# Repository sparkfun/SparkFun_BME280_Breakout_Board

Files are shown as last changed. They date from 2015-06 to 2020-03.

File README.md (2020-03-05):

SparkFun BME280
===============

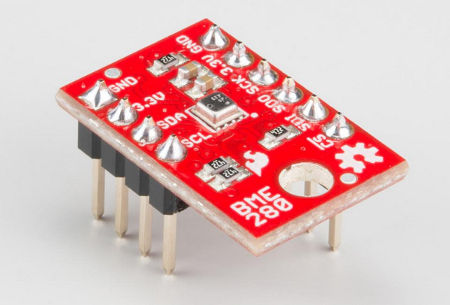
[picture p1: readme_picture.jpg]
SparkFun BME280 Breakout


[*SparkFun BME280 (SEN-13676)*](https://www.sparkfun.com/products/13676)

The Bosch BME280 sensor measures atmospheric pressure from 30kPa to 110kPa as well as relative humidity and temperature.  The SparkFun breakout provides a 3.3v SPI interface and a 5v tolerant I2C interface (has pull-up resistors to 3.3v).

Repository Contents
-------------------

* **/Documentation** - Data sheets, additional product information
* **/Hardware** - Eagle design files (.brd, .sch)
* **/Production** - Production panel files (.brd)

Documentation
--------------
* **[Library](https://github.com/sparkfun/SparkFun_BME280_Arduino_Library)** - Arduino library for the BME280.
* **[Hookup Guide](https://learn.sparkfun.com/tutorials/bme280-breakout-hookup-guide)** - Basic hookup guide for the SparkFun BME280.
* **[SparkFun Fritzing repo](https://github.com/sparkfun/Fritzing_Parts)** - Fritzing diagrams for SparkFun products.
* **[SparkFun 3D Model repo](https://github.com/sparkfun/3D_Models)** - 3D models of SparkFun products. 

Product Versions
----------------
* [*SEN-13676*](https://www.sparkfun.com/products/13676)

Version History
---------------

* [V_1.0.0](https://github.com/sparkfun/SparkFun_BME280_Breakout_Board/tree/V_1.0.0) - Public release.
* [V_1.1.0](https://github.com/sparkfun/SparkFun_BME280_Breakout_Board/tree/V_1.1.0) - Squashed arduino library changes.

License Information
-------------------

This product is _**open source**_! 

Please review the LICENSE.md file for license information. 

If you have any questions or concerns on licensing, please contact techsupport@sparkfun.com.

Distributed as-is; no warranty is given.

- Your friends at SparkFun.

_<COLLABORATION CREDIT>_

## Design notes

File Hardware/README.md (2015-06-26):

SparkFun <PRODUCT NAME> Design Files
=====================================

The .sch and .brd files hare are Eagle CAD schematic and PCB design files from SparkFun Electronics.
A freeware version of Eagle can be found [here](http://www.cadsoftusa.com/download-eagle/freeware/).

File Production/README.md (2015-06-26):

SparkFun <PRODUCT NAME> Production Files
=========================================

These are the production files SparkFun uses for printing PCBs.

License Information
-------------------
This product is open source! 

The hardware is released under [Creative Commons ShareAlike 4.0 International](https://creativecommons.org/licenses/by-sa/4.0/).

Please use, reuse, and modify these files as you see fit. Please maintain attribution to SparkFun Electronics and release anything derivative under the same license.

Distributed as-is; no warranty is given.

- Your friends at SparkFun.

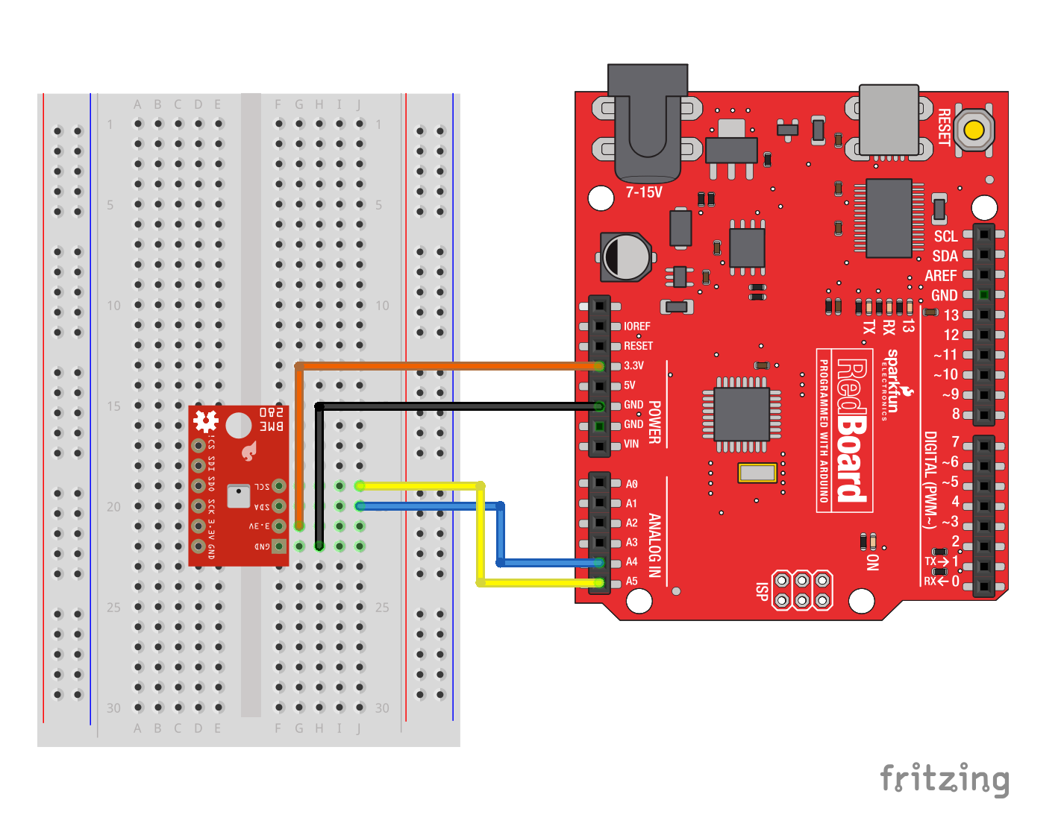
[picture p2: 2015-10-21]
Documentation/Fritzing/RedboardI2C_bb.png

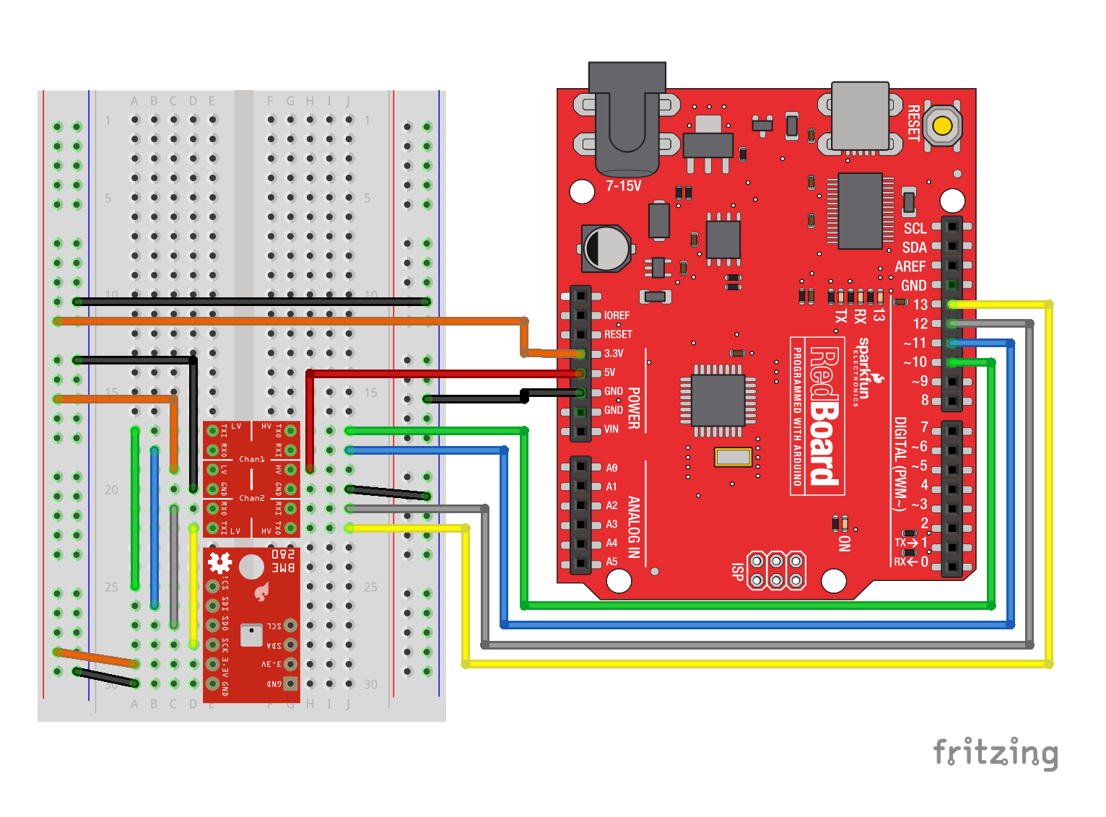
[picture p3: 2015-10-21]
Documentation/Fritzing/RedboardSPI_bb.png

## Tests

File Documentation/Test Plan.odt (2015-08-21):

# Functional Testing Plan

## Code Things to Verify

- Are the readings beliveable over I2C @ 100 KHz?
- Are the readings believable over SPI?
- All address options function with driver

## HW Things to Verify

- Power consumption
- I2C signal integrity
- SPI signal integrity

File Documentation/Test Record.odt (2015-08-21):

# Functional Test Record

Marshall Taylor

8/21/2015

HW version v02

## Testing with I2C mode

#### Test the I2C Addressing

Procedure:

1. Use ReadAllData sketch with default HW
2. Test default condition
3. Switch address jumper
4. Change address in code
5. Test alternate address

Criteria:

1. Did the modes work? YES
2. Does the silkscreen match the operation? YES

#### Signal Integrity of I2C lines

Procedure:

1. Attach scope probes to SDA and SCL with the shortest wire possible
2. Capture a full operation
3. Capture a zoom of 3 consecutively toggling SDA bits

Criteria:

1. Are I2C interface rise times are far below clk pulse high width?
2. Record the pullup resistor value as measured:
- 1: 4.692 kOhm
- 2: 4.698 kOhm

## Testing with SPI mode

Procedure:

1. Connect the BME280 to an arduino through the level shifter
2. Attach scope probes to MOSI, MISO, CS, and CLK on the BME280 side
3. Capture a full operation
4. Capture a zoom of 3 consecutively toggling data bits for MISO
5. Capture a zoom of 3 consecutively toggling data bits for MOSI

Criteria:

1. Does the clock phase and polarity match the datasheets? YES, phase defined by clk state after SS goes low
2. Include the captures.

## Power Consumption

Procedure:

1. Measure the current draw before the IC is configured
2. Configure and spam read the data
3. Measure the current draw during spam read

Criteria:

1. Are both numbers below 5mA?
2. Record both currents
- Idle: ~1.5mA
- Max: ~2.0mA

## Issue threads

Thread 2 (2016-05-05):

readFloatHumidity doesn't return decimals

TheAustrian, 2016-05-05:
Hi! First of all thanks for the library!

I used the code from one of your examples to read the humidity into an array I initialized as follows:
`float humidityBuffer[buffersize+1] = {0.0};`
and later I read from the sensor with:
`humidityBuffer[bufferposition] = mySensor.readFloatHumidity();`
and I get values like "38" but with no decimal places. It works for temperature and with a division by 100 for pressure in hectopascals as well.

What am I doing wrong or is this an error in the library? I'm using the version from the library manager in Arduino IDE.

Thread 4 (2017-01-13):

Humidity randomly starts reading incorrectly

handsomedave, 2017-01-13:
I have two ESP8266 Things with one each BME280 on each device. They are reading Temp/Humidity/Pressure with i2c and logging it to a web service. Randomly one of them will start reading about 50% higher than the other. If I power cycle the Thing it then reads correctly for a random amount of time before again reading incorrectly. It has started to read incorrectly in as little as 5 minutes or as much as 20 hours. I doesn't slowly start drifting away from a correct reading, it just all at once jumps 50% or so.

I have swapped sensors between devices and it seems to only occur with one of the Things regardless of which sensor is hooked up. Other than the two constants used to identify the specific device and sensor the code running on the Things is identical.

santaimpersonator, 2019-12-30:
Based on your explanation of your issue, it sounds like it is an issue with the "ESP8266 Thing". I am closing out this GitHub issue since it doesn't sound like it is related to the BME280; feel free to re-open the issue if necessary. Otherwise, if you are looking for technical assistance, please create a post on our [forum](https://forum.sparkfun.com/).

Closed 2019-12-30.

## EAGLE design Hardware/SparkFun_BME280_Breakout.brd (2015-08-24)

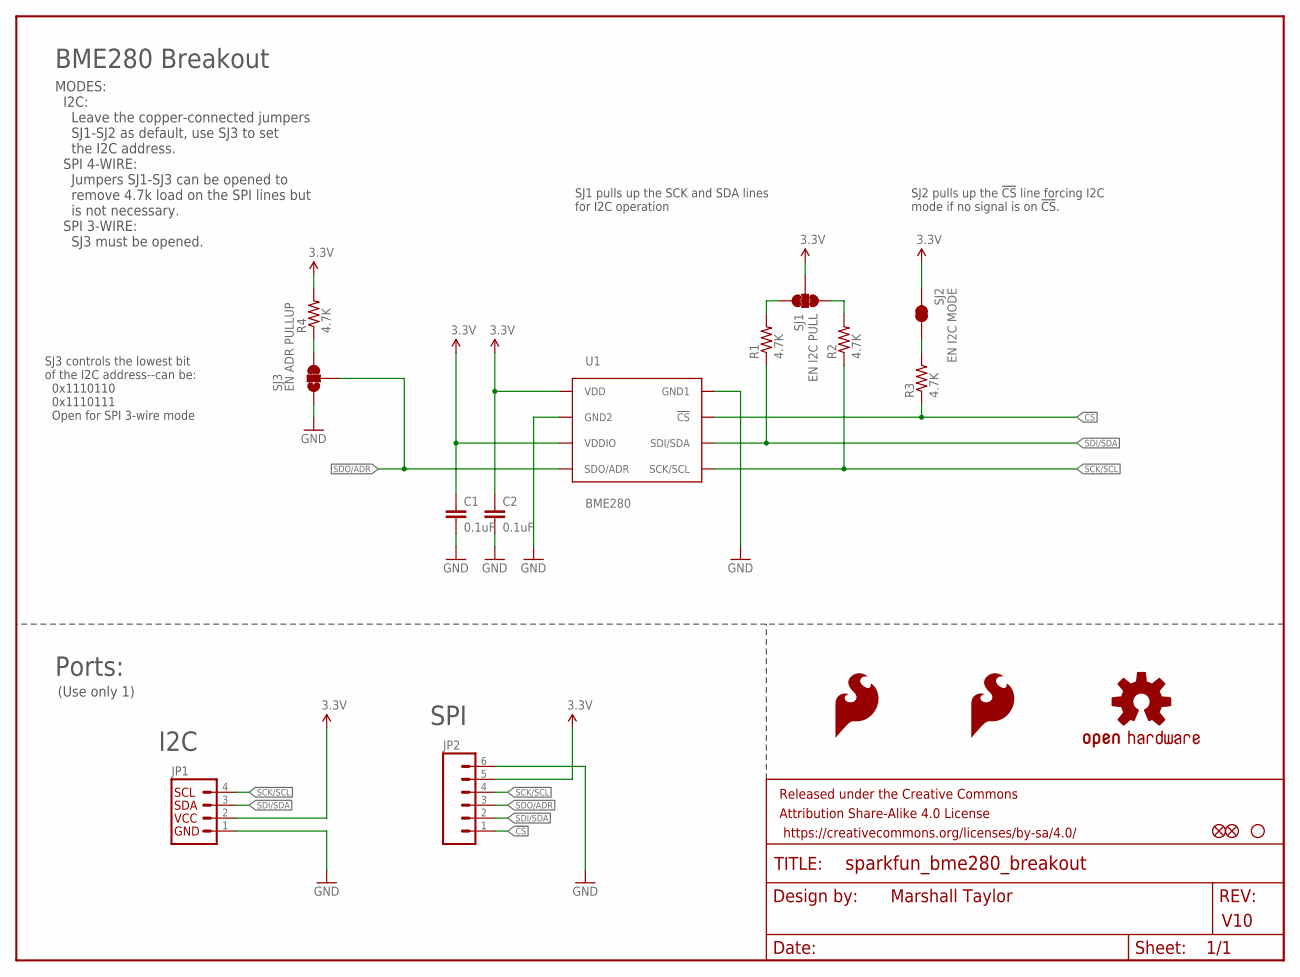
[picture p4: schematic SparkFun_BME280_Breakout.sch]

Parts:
C1, C2: 0.1uF; 0603-CAP
FID1, FID2: FIDUCIAL1X2; FIDUCIAL-1X2
FRAME1: FRAME-LETTER; CREATIVE_COMMONS
JP1: I2C_STANDARD_NO_SILK; 1X04_NO_SILK
JP2: M06NO_SILK_FEMALE_PTH; 1X06_NO_SILK
LOGO1, LOGO2: SFE_LOGO_FLAME.1_INCH; SFE_LOGO_FLAME_.1
LOGO3: OSHW-LOGOS; OSHW-LOGO-S
R1, R2, R3, R4: 4.7K; 0603-RES
SJ1: EN I2C PULL; PAD-JUMPER-3-3OF3_NC_BY_TRACE_YES_SILK_FULL_BOX
SJ2: EN I2C MODE; PAD-JUMPER-2-NC_BY_TRACE_YES_SILK
SJ3: EN ADR PULLUP; PAD-JUMPER-3-2OF3_NC_BY_TRACE_YES_SILK_FULL_BOX
STANDOFF4: STAND-OFF
U1: BME280; BME280_LGA

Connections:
3.3V: C1.1, C2.1, JP1.2, JP2.5, R4.2, SJ1.2, SJ2.2, U1.P$6 (VDDIO), U1.P$8 (VDD)
!CS: JP2.1, R3.1, U1.P$2 (!CS)
GND: C1.2, C2.2, JP1.1, JP2.6, SJ3.1, U1.P$1 (GND1), U1.P$7 (GND2)
unnamed: R1.2, SJ1.3
unnamed: R2.2, SJ1.1
unnamed: R3.2, SJ2.1
unnamed: R4.1, SJ3.3
SCK/SCL: JP1.4, JP2.4, R2.1, U1.P$4 (SCK/SCL)
SDI/SDA: JP1.3, JP2.2, R1.1, U1.P$3 (SDI/SDA)
SDO/ADR: JP2.3, SJ3.2, U1.P$5 (SDO/ADR)

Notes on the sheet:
Marshall Taylor
V10
BME280 Breakout
SJ3 controls the lowest bit of the I2C address--can be: 0x1110110 0x1110111 Open for SPI 3-wire mode
SJ1 pulls up the SCK and SDA lines for I2C operation
Ports:
(Use only 1)
I2C
SPI
MODES: I2C: Leave the copper-connected jumpers SJ1-SJ2 as default, use SJ3 to set the I2C address. SPI 4-WIRE: Jumpers SJ1-SJ3 can be opened to remove 4.7k load on the SPI lines but is not necessary. SPI 3-WIRE: SJ3 must be opened.
SJ2 pulls up the !CS! line forcing I2C mode if no signal is on !CS!.

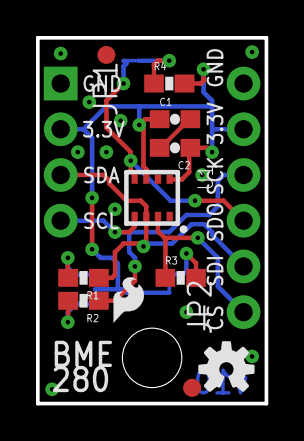
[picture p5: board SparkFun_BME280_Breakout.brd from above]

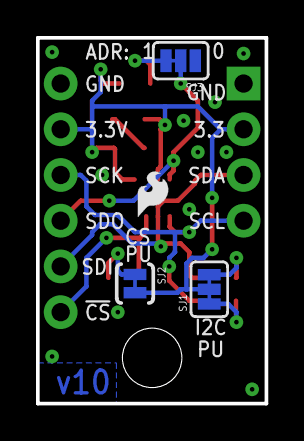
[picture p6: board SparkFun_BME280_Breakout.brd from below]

Board: 2 copper layers, 12.7 x 20.3 mm, 19 parts (4 on the bottom side), 10 nets.

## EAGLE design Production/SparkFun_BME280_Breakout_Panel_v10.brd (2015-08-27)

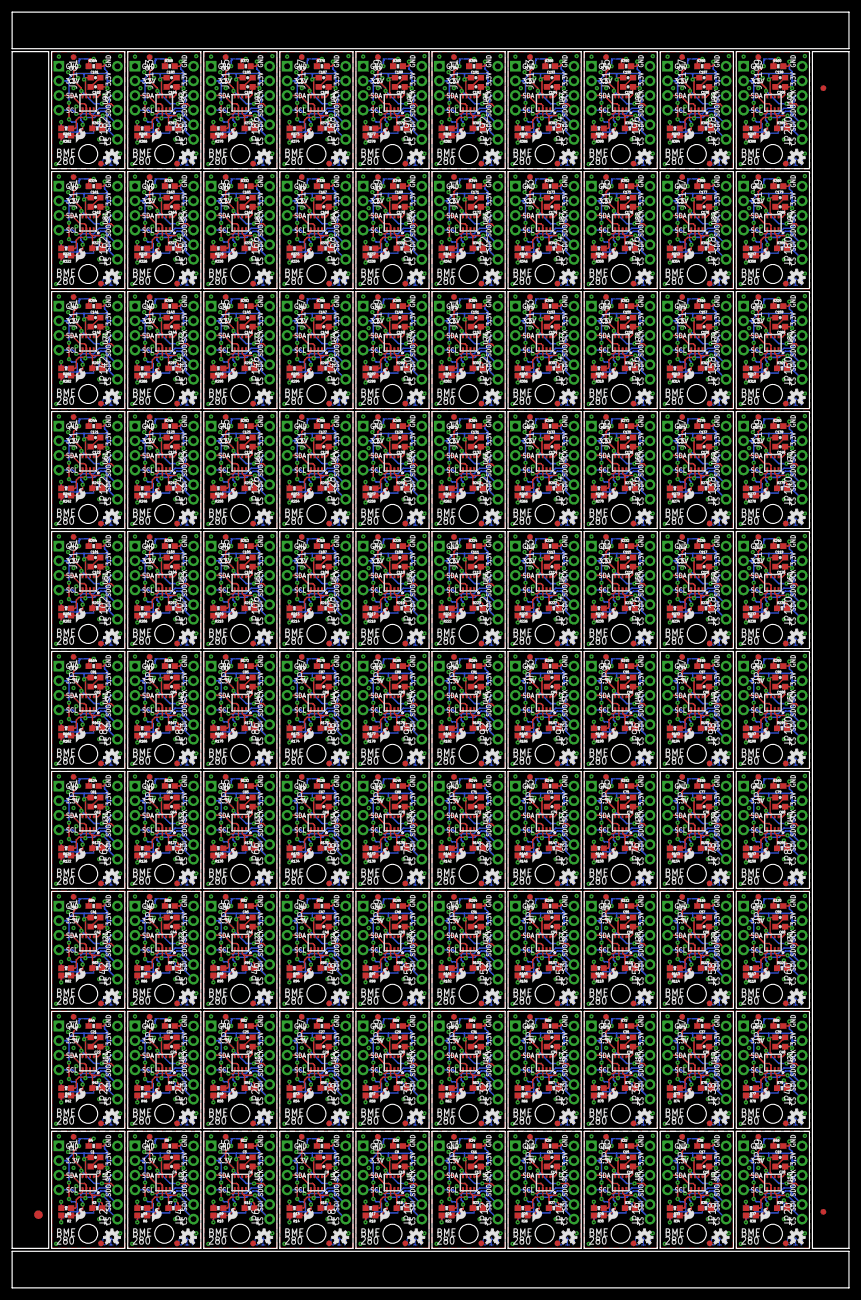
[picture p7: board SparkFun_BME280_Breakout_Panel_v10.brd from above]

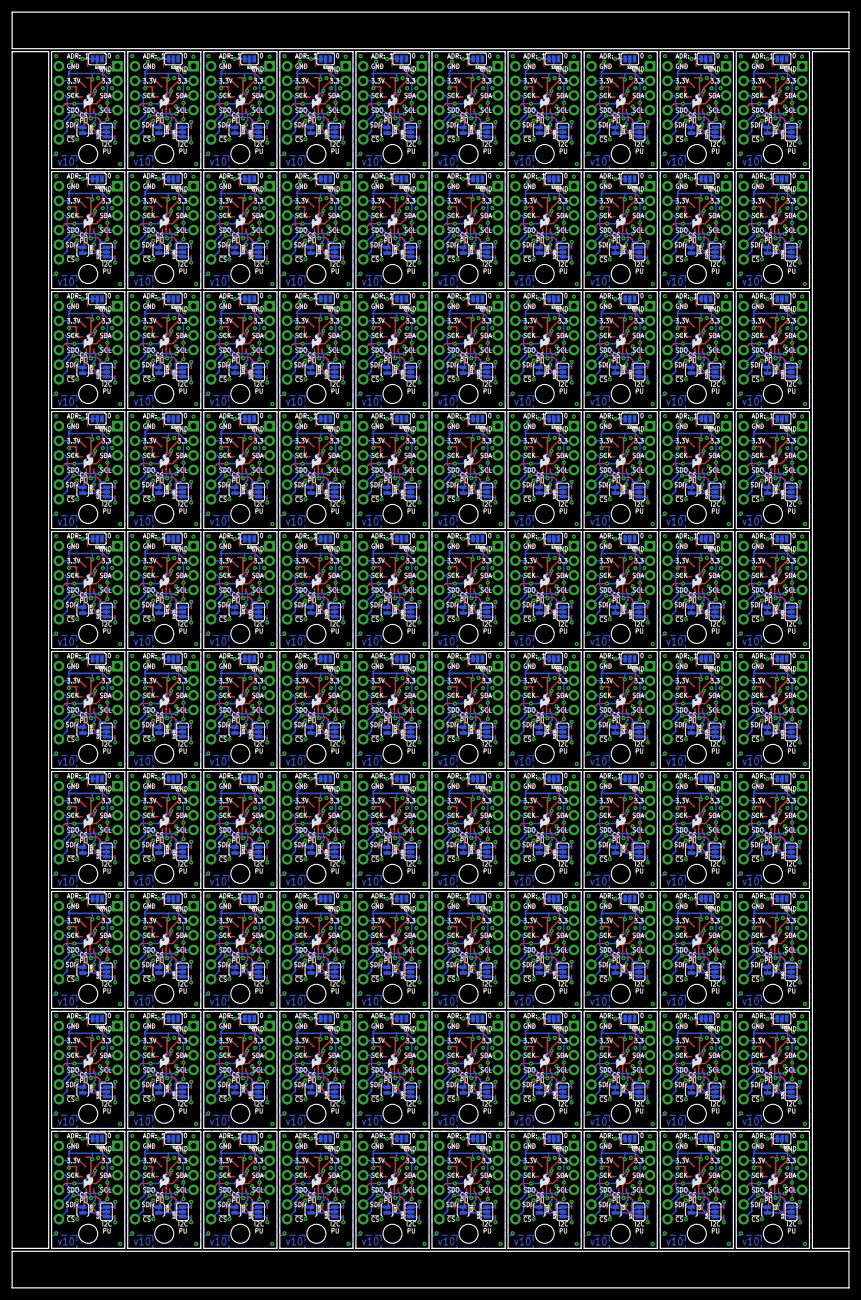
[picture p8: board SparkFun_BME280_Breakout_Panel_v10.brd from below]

Board: 2 copper layers, 145.3 x 221.5 mm, 1803 parts (400 on the bottom side), 1000 nets.

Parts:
C1, C2, C3, C4, C5, C6, C7, C8, C9, C10, C11, C12, C13, C14, C15, C16, C17, C18, C19, C20, C21, C22, C23, C24, C25, C26, C27, C28, C29, C30, C31, C32, C33, C34, C35, C36, C37, C38, C39, C40, C41, C42, C43, C44, C45, C46, C47, C48, C49, C50, C51, C52, C53, C54, C55, C56, C57, C58, C59, C60, C61, C62, C63, C64, C65, C66, C67, C68, C69, C70, C71, C72, C73, C74, C75, C76, C77, C78, C79, C80, C81, C82, C83, C84, C85, C86, C87, C88, C89, C90, C91, C92, C93, C94, C95, C96, C97, C98, C99, C100, C101, C102, C103, C104, C105, C106, C107, C108, C109, C110, C111, C112, C113, C114, C115, C116, C117, C118, C119, C120, C121, C122, C123, C124, C125, C126, C127, C128, C129, C130, C131, C132, C133, C134, C135, C136, C137, C138, C139, C140, C141, C142, C143, C144, C145, C146, C147, C148, C149, C150, C151, C152, C153, C154, C155, C156, C157, C158, C159, C160, C161, C162, C163, C164, C165, C166, C167, C168, C169, C170, C171, C172, C173, C174, C175, C176, C177, C178, C179, C180, C181, C182, C183, C184, C185, C186, C187, C188, C189, C190, C191, C192, C193, C194, C195, C196, C197, C198, C199, C200: 0.1uF; 0603-CAP
E$1: FIDUCIAL-1.5X3
E$5, E$6: FIDUCIAL-1X2
FID1, FID2, FID3, FID4, FID5, FID6, FID7, FID8, FID9, FID10, FID11, FID12, FID13, FID14, FID15, FID16, FID17, FID18, FID19, FID20, FID21, FID22, FID23, FID24, FID25, FID26, FID27, FID28, FID29, FID30, FID31, FID32, FID33, FID34, FID35, FID36, FID37, FID38, FID39, FID40, FID41, FID42, FID43, FID44, FID45, FID46, FID47, FID48, FID49, FID50, FID51, FID52, FID53, FID54, FID55, FID56, FID57, FID58, FID59, FID60, FID61, FID62, FID63, FID64, FID65, FID66, FID67, FID68, FID69, FID70, FID71, FID72, FID73, FID74, FID75, FID76, FID77, FID78, FID79, FID80, FID81, FID82, FID83, FID84, FID85, FID86, FID87, FID88, FID89, FID90, FID91, FID92, FID93, FID94, FID95, FID96, FID97, FID98, FID99, FID100, FID101, FID102, FID103, FID104, FID105, FID106, FID107, FID108, FID109, FID110, FID111, FID112, FID113, FID114, FID115, FID116, FID117, FID118, FID119, FID120, FID121, FID122, FID123, FID124, FID125, FID126, FID127, FID128, FID129, FID130, FID131, FID132, FID133, FID134, FID135, FID136, FID137, FID138, FID139, FID140, FID141, FID142, FID143, FID144, FID145, FID146, FID147, FID148, FID149, FID150, FID151, FID152, FID153, FID154, FID155, FID156, FID157, FID158, FID159, FID160, FID161, FID162, FID163, FID164, FID165, FID166, FID167, FID168, FID169, FID170, FID171, FID172, FID173, FID174, FID175, FID176, FID177, FID178, FID179, FID180, FID181, FID182, FID183, FID184, FID185, FID186, FID187, FID188, FID189, FID190, FID191, FID192, FID193, FID194, FID195, FID196, FID197, FID198, FID199, FID200: FIDUCIAL1X2; FIDUCIAL-1X2
JP1, JP3, JP5, JP7, JP9, JP11, JP13, JP15, JP17, JP19, JP21, JP23, JP25, JP27, JP29, JP31, JP33, JP35, JP37, JP39, JP41, JP43, JP45, JP47, JP49, JP51, JP53, JP55, JP57, JP59, JP61, JP63, JP65, JP67, JP69, JP71, JP73, JP75, JP77, JP79, JP81, JP83, JP85, JP87, JP89, JP91, JP93, JP95, JP97, JP99, JP101, JP103, JP105, JP107, JP109, JP111, JP113, JP115, JP117, JP119, JP121, JP123, JP125, JP127, JP129, JP131, JP133, JP135, JP137, JP139, JP141, JP143, JP145, JP147, JP149, JP151, JP153, JP155, JP157, JP159, JP161, JP163, JP165, JP167, JP169, JP171, JP173, JP175, JP177, JP179, JP181, JP183, JP185, JP187, JP189, JP191, JP193, JP195, JP197, JP199: 1X04_NO_SILK
JP2, JP4, JP6, JP8, JP10, JP12, JP14, JP16, JP18, JP20, JP22, JP24, JP26, JP28, JP30, JP32, JP34, JP36, JP38, JP40, JP42, JP44, JP46, JP48, JP50, JP52, JP54, JP56, JP58, JP60, JP62, JP64, JP66, JP68, JP70, JP72, JP74, JP76, JP78, JP80, JP82, JP84, JP86, JP88, JP90, JP92, JP94, JP96, JP98, JP100, JP102, JP104, JP106, JP108, JP110, JP112, JP114, JP116, JP118, JP120, JP122, JP124, JP126, JP128, JP130, JP132, JP134, JP136, JP138, JP140, JP142, JP144, JP146, JP148, JP150, JP152, JP154, JP156, JP158, JP160, JP162, JP164, JP166, JP168, JP170, JP172, JP174, JP176, JP178, JP180, JP182, JP184, JP186, JP188, JP190, JP192, JP194, JP196, JP198, JP200: 1X06_NO_SILK
LOGO1, LOGO2, LOGO4, LOGO5, LOGO7, LOGO8, LOGO10, LOGO11, LOGO13, LOGO14, LOGO16, LOGO17, LOGO19, LOGO20, LOGO22, LOGO23, LOGO25, LOGO26, LOGO28, LOGO29, LOGO31, LOGO32, LOGO34, LOGO35, LOGO37, LOGO38, LOGO40, LOGO41, LOGO43, LOGO44, LOGO46, LOGO47, LOGO49, LOGO50, LOGO52, LOGO53, LOGO55, LOGO56, LOGO58, LOGO59, LOGO61, LOGO62, LOGO64, LOGO65, LOGO67, LOGO68, LOGO70, LOGO71, LOGO73, LOGO74, LOGO76, LOGO77, LOGO79, LOGO80, LOGO82, LOGO83, LOGO85, LOGO86, LOGO88, LOGO89, LOGO91, LOGO92, LOGO94, LOGO95, LOGO97, LOGO98, LOGO100, LOGO101, LOGO103, LOGO104, LOGO106, LOGO107, LOGO109, LOGO110, LOGO112, LOGO113, LOGO115, LOGO116, LOGO118, LOGO119, LOGO121, LOGO122, LOGO124, LOGO125, LOGO127, LOGO128, LOGO130, LOGO131, LOGO133, LOGO134, LOGO136, LOGO137, LOGO139, LOGO140, LOGO142, LOGO143, LOGO145, LOGO146, LOGO148, LOGO149, LOGO151, LOGO152, LOGO154, LOGO155, LOGO157, LOGO158, LOGO160, LOGO161, LOGO163, LOGO164, LOGO166, LOGO167, LOGO169, LOGO170, LOGO172, LOGO173, LOGO175, LOGO176, LOGO178, LOGO179, LOGO181, LOGO182, LOGO184, LOGO185, LOGO187, LOGO188, LOGO190, LOGO191, LOGO193, LOGO194, LOGO196, LOGO197, LOGO199, LOGO200, LOGO202, LOGO203, LOGO205, LOGO206, LOGO208, LOGO209, LOGO211, LOGO212, LOGO214, LOGO215, LOGO217, LOGO218, LOGO220, LOGO221, LOGO223, LOGO224, LOGO226, LOGO227, LOGO229, LOGO230, LOGO232, LOGO233, LOGO235, LOGO236, LOGO238, LOGO239, LOGO241, LOGO242, LOGO244, LOGO245, LOGO247, LOGO248, LOGO250, LOGO251, LOGO253, LOGO254, LOGO256, LOGO257, LOGO259, LOGO260, LOGO262, LOGO263, LOGO265, LOGO266, LOGO268, LOGO269, LOGO271, LOGO272, LOGO274, LOGO275, LOGO277, LOGO278, LOGO280, LOGO281, LOGO283, LOGO284, LOGO286, LOGO287, LOGO289, LOGO290, LOGO292, LOGO293, LOGO295, LOGO296, LOGO298, LOGO299: SFE_LOGO_FLAME.1_INCH; SFE_LOGO_FLAME_.1
LOGO3, LOGO6, LOGO9, LOGO12, LOGO15, LOGO18, LOGO21, LOGO24, LOGO27, LOGO30, LOGO33, LOGO36, LOGO39, LOGO42, LOGO45, LOGO48, LOGO51, LOGO54, LOGO57, LOGO60, LOGO63, LOGO66, LOGO69, LOGO72, LOGO75, LOGO78, LOGO81, LOGO84, LOGO87, LOGO90, LOGO93, LOGO96, LOGO99, LOGO102, LOGO105, LOGO108, LOGO111, LOGO114, LOGO117, LOGO120, LOGO123, LOGO126, LOGO129, LOGO132, LOGO135, LOGO138, LOGO141, LOGO144, LOGO147, LOGO150, LOGO153, LOGO156, LOGO159, LOGO162, LOGO165, LOGO168, LOGO171, LOGO174, LOGO177, LOGO180, LOGO183, LOGO186, LOGO189, LOGO192, LOGO195, LOGO198, LOGO201, LOGO204, LOGO207, LOGO210, LOGO213, LOGO216, LOGO219, LOGO222, LOGO225, LOGO228, LOGO231, LOGO234, LOGO237, LOGO240, LOGO243, LOGO246, LOGO249, LOGO252, LOGO255, LOGO258, LOGO261, LOGO264, LOGO267, LOGO270, LOGO273, LOGO276, LOGO279, LOGO282, LOGO285, LOGO288, LOGO291, LOGO294, LOGO297, LOGO300: OSHW-LOGOS; OSHW-LOGO-S
R1, R2, R3, R4, R5, R6, R7, R8, R9, R10, R11, R12, R13, R14, R15, R16, R17, R18, R19, R20, R21, R22, R23, R24, R25, R26, R27, R28, R29, R30, R31, R32, R33, R34, R35, R36, R37, R38, R39, R40, R41, R42, R43, R44, R45, R46, R47, R48, R49, R50, R51, R52, R53, R54, R55, R56, R57, R58, R59, R60, R61, R62, R63, R64, R65, R66, R67, R68, R69, R70, R71, R72, R73, R74, R75, R76, R77, R78, R79, R80, R81, R82, R83, R84, R85, R86, R87, R88, R89, R90, R91, R92, R93, R94, R95, R96, R97, R98, R99, R100, R101, R102, R103, R104, R105, R106, R107, R108, R109, R110, R111, R112, R113, R114, R115, R116, R117, R118, R119, R120, R121, R122, R123, R124, R125, R126, R127, R128, R129, R130, R131, R132, R133, R134, R135, R136, R137, R138, R139, R140, R141, R142, R143, R144, R145, R146, R147, R148, R149, R150, R151, R152, R153, R154, R155, R156, R157, R158, R159, R160, R161, R162, R163, R164, R165, R166, R167, R168, R169, R170, R171, R172, R173, R174, R175, R176, R177, R178, R179, R180, R181, R182, R183, R184, R185, R186, R187, R188, R189, R190, R191, R192, R193, R194, R195, R196, R197, R198, R199, R200, R201, R202, R203, R204, R205, R206, R207, R208, R209, R210, R211, R212, R213, R214, R215, R216, R217, R218, R219, R220, R221, R222, R223, R224, R225, R226, R227, R228, R229, R230, R231, R232, R233, R234, R235, R236, R237, R238, R239, R240, R241, R242, R243, R244, R245, R246, R247, R248, R249, R250, R251, R252, R253, R254, R255, R256, R257, R258, R259, R260, R261, R262, R263, R264, R265, R266, R267, R268, R269, R270, R271, R272, R273, R274, R275, R276, R277, R278, R279, R280, R281, R282, R283, R284, R285, R286, R287, R288, R289, R290, R291, R292, R293, R294, R295, R296, R297, R298, R299, R300, R301, R302, R303, R304, R305, R306, R307, R308, R309, R310, R311, R312, R313, R314, R315, R316, R317, R318, R319, R320, R321, R322, R323, R324, R325, R326, R327, R328, R329, R330, R331, R332, R333, R334, R335, R336, R337, R338, R339, R340, R341, R342, R343, R344, R345, R346, R347, R348, R349, R350, R351, R352, R353, R354, R355, R356, R357, R358, R359, R360, R361, R362, R363, R364, R365, R366, R367, R368, R369, R370, R371, R372, R373, R374, R375, R376, R377, R378, R379, R380, R381, R382, R383, R384, R385, R386, R387, R388, R389, R390, R391, R392, R393, R394, R395, R396, R397, R398, R399, R400: 4.7K; 0603-RES
SJ1, SJ4, SJ7, SJ10, SJ13, SJ16, SJ19, SJ22, SJ25, SJ28, SJ31, SJ34, SJ37, SJ40, SJ43, SJ46, SJ49, SJ52, SJ55, SJ58, SJ61, SJ64, SJ67, SJ70, SJ73, SJ76, SJ79, SJ82, SJ85, SJ88, SJ91, SJ94, SJ97, SJ100, SJ103, SJ106, SJ109, SJ112, SJ115, SJ118, SJ121, SJ124, SJ127, SJ130, SJ133, SJ136, SJ139, SJ142, SJ145, SJ148, SJ151, SJ154, SJ157, SJ160, SJ163, SJ166, SJ169, SJ172, SJ175, SJ178, SJ181, SJ184, SJ187, SJ190, SJ193, SJ196, SJ199, SJ202, SJ205, SJ208, SJ211, SJ214, SJ217, SJ220, SJ223, SJ226, SJ229, SJ232, SJ235, SJ238, SJ241, SJ244, SJ247, SJ250, SJ253, SJ256, SJ259, SJ262, SJ265, SJ268, SJ271, SJ274, SJ277, SJ280, SJ283, SJ286, SJ289, SJ292, SJ295, SJ298: EN I2C PULL; PAD-JUMPER-3-3OF3_NC_BY_TRACE_YES_SILK_FULL_BOX
SJ2, SJ5, SJ8, SJ11, SJ14, SJ17, SJ20, SJ23, SJ26, SJ29, SJ32, SJ35, SJ38, SJ41, SJ44, SJ47, SJ50, SJ53, SJ56, SJ59, SJ62, SJ65, SJ68, SJ71, SJ74, SJ77, SJ80, SJ83, SJ86, SJ89, SJ92, SJ95, SJ98, SJ101, SJ104, SJ107, SJ110, SJ113, SJ116, SJ119, SJ122, SJ125, SJ128, SJ131, SJ134, SJ137, SJ140, SJ143, SJ146, SJ149, SJ152, SJ155, SJ158, SJ161, SJ164, SJ167, SJ170, SJ173, SJ176, SJ179, SJ182, SJ185, SJ188, SJ191, SJ194, SJ197, SJ200, SJ203, SJ206, SJ209, SJ212, SJ215, SJ218, SJ221, SJ224, SJ227, SJ230, SJ233, SJ236, SJ239, SJ242, SJ245, SJ248, SJ251, SJ254, SJ257, SJ260, SJ263, SJ266, SJ269, SJ272, SJ275, SJ278, SJ281, SJ284, SJ287, SJ290, SJ293, SJ296, SJ299: EN I2C MODE; PAD-JUMPER-2-NC_BY_TRACE_YES_SILK
SJ3, SJ6, SJ9, SJ12, SJ15, SJ18, SJ21, SJ24, SJ27, SJ30, SJ33, SJ36, SJ39, SJ42, SJ45, SJ48, SJ51, SJ54, SJ57, SJ60, SJ63, SJ66, SJ69, SJ72, SJ75, SJ78, SJ81, SJ84, SJ87, SJ90, SJ93, SJ96, SJ99, SJ102, SJ105, SJ108, SJ111, SJ114, SJ117, SJ120, SJ123, SJ126, SJ129, SJ132, SJ135, SJ138, SJ141, SJ144, SJ147, SJ150, SJ153, SJ156, SJ159, SJ162, SJ165, SJ168, SJ171, SJ174, SJ177, SJ180, SJ183, SJ186, SJ189, SJ192, SJ195, SJ198, SJ201, SJ204, SJ207, SJ210, SJ213, SJ216, SJ219, SJ222, SJ225, SJ228, SJ231, SJ234, SJ237, SJ240, SJ243, SJ246, SJ249, SJ252, SJ255, SJ258, SJ261, SJ264, SJ267, SJ270, SJ273, SJ276, SJ279, SJ282, SJ285, SJ288, SJ291, SJ294, SJ297, SJ300: EN ADR PULLUP; PAD-JUMPER-3-2OF3_NC_BY_TRACE_YES_SILK_FULL_BOX
STANDOFF1, STANDOFF2, STANDOFF3, STANDOFF4, STANDOFF5, STANDOFF6, STANDOFF7, STANDOFF8, STANDOFF9, STANDOFF10, STANDOFF11, STANDOFF12, STANDOFF13, STANDOFF14, STANDOFF15, STANDOFF16, STANDOFF17, STANDOFF18, STANDOFF19, STANDOFF20, STANDOFF21, STANDOFF22, STANDOFF23, STANDOFF24, STANDOFF25, STANDOFF26, STANDOFF27, STANDOFF28, STANDOFF29, STANDOFF30, STANDOFF31, STANDOFF32, STANDOFF33, STANDOFF34, STANDOFF35, STANDOFF36, STANDOFF37, STANDOFF38, STANDOFF39, STANDOFF40, STANDOFF41, STANDOFF42, STANDOFF43, STANDOFF44, STANDOFF45, STANDOFF46, STANDOFF47, STANDOFF48, STANDOFF49, STANDOFF50, STANDOFF51, STANDOFF52, STANDOFF53, STANDOFF54, STANDOFF55, STANDOFF56, STANDOFF57, STANDOFF58, STANDOFF59, STANDOFF60, STANDOFF61, STANDOFF62, STANDOFF63, STANDOFF64, STANDOFF65, STANDOFF66, STANDOFF67, STANDOFF68, STANDOFF69, STANDOFF70, STANDOFF71, STANDOFF72, STANDOFF73, STANDOFF74, STANDOFF75, STANDOFF76, STANDOFF77, STANDOFF78, STANDOFF79, STANDOFF80, STANDOFF81, STANDOFF82, STANDOFF83, STANDOFF84, STANDOFF85, STANDOFF86, STANDOFF87, STANDOFF88, STANDOFF89, STANDOFF90, STANDOFF91, STANDOFF92, STANDOFF93, STANDOFF94, STANDOFF95, STANDOFF96, STANDOFF97, STANDOFF98, STANDOFF99, STANDOFF100: STAND-OFF
U1, U2, U3, U4, U5, U6, U7, U8, U9, U10, U11, U12, U13, U14, U15, U16, U17, U18, U19, U20, U21, U22, U23, U24, U25, U26, U27, U28, U29, U30, U31, U32, U33, U34, U35, U36, U37, U38, U39, U40, U41, U42, U43, U44, U45, U46, U47, U48, U49, U50, U51, U52, U53, U54, U55, U56, U57, U58, U59, U60, U61, U62, U63, U64, U65, U66, U67, U68, U69, U70, U71, U72, U73, U74, U75, U76, U77, U78, U79, U80, U81, U82, U83, U84, U85, U86, U87, U88, U89, U90, U91, U92, U93, U94, U95, U96, U97, U98, U99, U100: BME280; BME280_LGA

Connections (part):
3.3V: C1.1, C2.1, JP1.2, JP2.5, R4.2, SJ1.2, SJ2.2, U1.P$6, U1.P$8
3.3V1: C3.1, C4.1, JP3.2, JP4.5, R8.2, SJ4.2, SJ5.2, U2.P$6, U2.P$8
3.3V2: C5.1, C6.1, JP5.2, JP6.5, R12.2, SJ7.2, SJ8.2, U3.P$6, U3.P$8
3.3V3: C7.1, C8.1, JP7.2, JP8.5, R16.2, SJ10.2, SJ11.2, U4.P$6, U4.P$8
3.3V4: C9.1, C10.1, JP9.2, JP10.5, R20.2, SJ13.2, SJ14.2, U5.P$6, U5.P$8
3.3V5: C11.1, C12.1, JP11.2, JP12.5, R24.2, SJ16.2, SJ17.2, U6.P$6, U6.P$8
3.3V6: C13.1, C14.1, JP13.2, JP14.5, R28.2, SJ19.2, SJ20.2, U7.P$6, U7.P$8
3.3V7: C15.1, C16.1, JP15.2, JP16.5, R32.2, SJ22.2, SJ23.2, U8.P$6, U8.P$8
3.3V8: C17.1, C18.1, JP17.2, JP18.5, R36.2, SJ25.2, SJ26.2, U9.P$6, U9.P$8
3.3V9: C19.1, C20.1, JP19.2, JP20.5, R40.2, SJ28.2, SJ29.2, U10.P$6, U10.P$8
3.3V10: C21.1, C22.1, JP21.2, JP22.5, R44.2, SJ31.2, SJ32.2, U11.P$6, U11.P$8
3.3V11: C23.1, C24.1, JP23.2, JP24.5, R48.2, SJ34.2, SJ35.2, U12.P$6, U12.P$8
3.3V12: C25.1, C26.1, JP25.2, JP26.5, R52.2, SJ37.2, SJ38.2, U13.P$6, U13.P$8
3.3V13: C27.1, C28.1, JP27.2, JP28.5, R56.2, SJ40.2, SJ41.2, U14.P$6, U14.P$8
3.3V14: C29.1, C30.1, JP29.2, JP30.5, R60.2, SJ43.2, SJ44.2, U15.P$6, U15.P$8
3.3V15: C31.1, C32.1, JP31.2, JP32.5, R64.2, SJ46.2, SJ47.2, U16.P$6, U16.P$8
3.3V16: C33.1, C34.1, JP33.2, JP34.5, R68.2, SJ49.2, SJ50.2, U17.P$6, U17.P$8
3.3V17: C35.1, C36.1, JP35.2, JP36.5, R72.2, SJ52.2, SJ53.2, U18.P$6, U18.P$8
3.3V18: C37.1, C38.1, JP37.2, JP38.5, R76.2, SJ55.2, SJ56.2, U19.P$6, U19.P$8
3.3V19: C39.1, C40.1, JP39.2, JP40.5, R80.2, SJ58.2, SJ59.2, U20.P$6, U20.P$8
3.3V20: C41.1, C42.1, JP41.2, JP42.5, R84.2, SJ61.2, SJ62.2, U21.P$6, U21.P$8
3.3V21: C43.1, C44.1, JP43.2, JP44.5, R88.2, SJ64.2, SJ65.2, U22.P$6, U22.P$8
3.3V22: C45.1, C46.1, JP45.2, JP46.5, R92.2, SJ67.2, SJ68.2, U23.P$6, U23.P$8
3.3V23: C47.1, C48.1, JP47.2, JP48.5, R96.2, SJ70.2, SJ71.2, U24.P$6, U24.P$8
3.3V24: C49.1, C50.1, JP49.2, JP50.5, R100.2, SJ73.2, SJ74.2, U25.P$6, U25.P$8
3.3V25: C51.1, C52.1, JP51.2, JP52.5, R104.2, SJ76.2, SJ77.2, U26.P$6, U26.P$8
3.3V26: C53.1, C54.1, JP53.2, JP54.5, R108.2, SJ79.2, SJ80.2, U27.P$6, U27.P$8
3.3V27: C55.1, C56.1, JP55.2, JP56.5, R112.2, SJ82.2, SJ83.2, U28.P$6, U28.P$8
3.3V28: C57.1, C58.1, JP57.2, JP58.5, R116.2, SJ85.2, SJ86.2, U29.P$6, U29.P$8
3.3V29: C59.1, C60.1, JP59.2, JP60.5, R120.2, SJ88.2, SJ89.2, U30.P$6, U30.P$8
3.3V30: C61.1, C62.1, JP61.2, JP62.5, R124.2, SJ91.2, SJ92.2, U31.P$6, U31.P$8
3.3V31: C63.1, C64.1, JP63.2, JP64.5, R128.2, SJ94.2, SJ95.2, U32.P$6, U32.P$8
3.3V32: C65.1, C66.1, JP65.2, JP66.5, R132.2, SJ97.2, SJ98.2, U33.P$6, U33.P$8
3.3V33: C67.1, C68.1, JP67.2, JP68.5, R136.2, SJ100.2, SJ101.2, U34.P$6, U34.P$8
3.3V34: C69.1, C70.1, JP69.2, JP70.5, R140.2, SJ103.2, SJ104.2, U35.P$6, U35.P$8
3.3V35: C71.1, C72.1, JP71.2, JP72.5, R144.2, SJ106.2, SJ107.2, U36.P$6, U36.P$8
3.3V36: C73.1, C74.1, JP73.2, JP74.5, R148.2, SJ109.2, SJ110.2, U37.P$6, U37.P$8
3.3V37: C75.1, C76.1, JP75.2, JP76.5, R152.2, SJ112.2, SJ113.2, U38.P$6, U38.P$8
3.3V38: C77.1, C78.1, JP77.2, JP78.5, R156.2, SJ115.2, SJ116.2, U39.P$6, U39.P$8
3.3V39: C79.1, C80.1, JP79.2, JP80.5, R160.2, SJ118.2, SJ119.2, U40.P$6, U40.P$8
3.3V40: C81.1, C82.1, JP81.2, JP82.5, R164.2, SJ121.2, SJ122.2, U41.P$6, U41.P$8
3.3V41: C83.1, C84.1, JP83.2, JP84.5, R168.2, SJ124.2, SJ125.2, U42.P$6, U42.P$8
3.3V42: C85.1, C86.1, JP85.2, JP86.5, R172.2, SJ127.2, SJ128.2, U43.P$6, U43.P$8
3.3V43: C87.1, C88.1, JP87.2, JP88.5, R176.2, SJ130.2, SJ131.2, U44.P$6, U44.P$8
3.3V44: C89.1, C90.1, JP89.2, JP90.5, R180.2, SJ133.2, SJ134.2, U45.P$6, U45.P$8
3.3V45: C91.1, C92.1, JP91.2, JP92.5, R184.2, SJ136.2, SJ137.2, U46.P$6, U46.P$8
3.3V46: C93.1, C94.1, JP93.2, JP94.5, R188.2, SJ139.2, SJ140.2, U47.P$6, U47.P$8
3.3V47: C95.1, C96.1, JP95.2, JP96.5, R192.2, SJ142.2, SJ143.2, U48.P$6, U48.P$8
3.3V48: C97.1, C98.1, JP97.2, JP98.5, R196.2, SJ145.2, SJ146.2, U49.P$6, U49.P$8
3.3V49: C99.1, C100.1, JP99.2, JP100.5, R200.2, SJ148.2, SJ149.2, U50.P$6, U50.P$8
3.3V50: C101.1, C102.1, JP101.2, JP102.5, R204.2, SJ151.2, SJ152.2, U51.P$6, U51.P$8
3.3V51: C103.1, C104.1, JP103.2, JP104.5, R208.2, SJ154.2, SJ155.2, U52.P$6, U52.P$8
3.3V52: C105.1, C106.1, JP105.2, JP106.5, R212.2, SJ157.2, SJ158.2, U53.P$6, U53.P$8
3.3V53: C107.1, C108.1, JP107.2, JP108.5, R216.2, SJ160.2, SJ161.2, U54.P$6, U54.P$8
3.3V54: C109.1, C110.1, JP109.2, JP110.5, R220.2, SJ163.2, SJ164.2, U55.P$6, U55.P$8
3.3V55: C111.1, C112.1, JP111.2, JP112.5, R224.2, SJ166.2, SJ167.2, U56.P$6, U56.P$8
3.3V56: C113.1, C114.1, JP113.2, JP114.5, R228.2, SJ169.2, SJ170.2, U57.P$6, U57.P$8
3.3V57: C115.1, C116.1, JP115.2, JP116.5, R232.2, SJ172.2, SJ173.2, U58.P$6, U58.P$8
3.3V58: C117.1, C118.1, JP117.2, JP118.5, R236.2, SJ175.2, SJ176.2, U59.P$6, U59.P$8
3.3V59: C119.1, C120.1, JP119.2, JP120.5, R240.2, SJ178.2, SJ179.2, U60.P$6, U60.P$8
3.3V60: C121.1, C122.1, JP121.2, JP122.5, R244.2, SJ181.2, SJ182.2, U61.P$6, U61.P$8
3.3V61: C123.1, C124.1, JP123.2, JP124.5, R248.2, SJ184.2, SJ185.2, U62.P$6, U62.P$8
3.3V62: C125.1, C126.1, JP125.2, JP126.5, R252.2, SJ187.2, SJ188.2, U63.P$6, U63.P$8
3.3V63: C127.1, C128.1, JP127.2, JP128.5, R256.2, SJ190.2, SJ191.2, U64.P$6, U64.P$8
3.3V64: C129.1, C130.1, JP129.2, JP130.5, R260.2, SJ193.2, SJ194.2, U65.P$6, U65.P$8
3.3V65: C131.1, C132.1, JP131.2, JP132.5, R264.2, SJ196.2, SJ197.2, U66.P$6, U66.P$8
3.3V66: C133.1, C134.1, JP133.2, JP134.5, R268.2, SJ199.2, SJ200.2, U67.P$6, U67.P$8
3.3V67: C135.1, C136.1, JP135.2, JP136.5, R272.2, SJ202.2, SJ203.2, U68.P$6, U68.P$8
3.3V68: C137.1, C138.1, JP137.2, JP138.5, R276.2, SJ205.2, SJ206.2, U69.P$6, U69.P$8
3.3V69: C139.1, C140.1, JP139.2, JP140.5, R280.2, SJ208.2, SJ209.2, U70.P$6, U70.P$8
3.3V70: C141.1, C142.1, JP141.2, JP142.5, R284.2, SJ211.2, SJ212.2, U71.P$6, U71.P$8
3.3V71: C143.1, C144.1, JP143.2, JP144.5, R288.2, SJ214.2, SJ215.2, U72.P$6, U72.P$8
3.3V72: C145.1, C146.1, JP145.2, JP146.5, R292.2, SJ217.2, SJ218.2, U73.P$6, U73.P$8
3.3V73: C147.1, C148.1, JP147.2, JP148.5, R296.2, SJ220.2, SJ221.2, U74.P$6, U74.P$8
3.3V74: C149.1, C150.1, JP149.2, JP150.5, R300.2, SJ223.2, SJ224.2, U75.P$6, U75.P$8
3.3V75: C151.1, C152.1, JP151.2, JP152.5, R304.2, SJ226.2, SJ227.2, U76.P$6, U76.P$8
3.3V76: C153.1, C154.1, JP153.2, JP154.5, R308.2, SJ229.2, SJ230.2, U77.P$6, U77.P$8
3.3V77: C155.1, C156.1, JP155.2, JP156.5, R312.2, SJ232.2, SJ233.2, U78.P$6, U78.P$8
3.3V78: C157.1, C158.1, JP157.2, JP158.5, R316.2, SJ235.2, SJ236.2, U79.P$6, U79.P$8
3.3V79: C159.1, C160.1, JP159.2, JP160.5, R320.2, SJ238.2, SJ239.2, U80.P$6, U80.P$8
3.3V80: C161.1, C162.1, JP161.2, JP162.5, R324.2, SJ241.2, SJ242.2, U81.P$6, U81.P$8
3.3V81: C163.1, C164.1, JP163.2, JP164.5, R328.2, SJ244.2, SJ245.2, U82.P$6, U82.P$8
3.3V82: C165.1, C166.1, JP165.2, JP166.5, R332.2, SJ247.2, SJ248.2, U83.P$6, U83.P$8
3.3V83: C167.1, C168.1, JP167.2, JP168.5, R336.2, SJ250.2, SJ251.2, U84.P$6, U84.P$8
3.3V84: C169.1, C170.1, JP169.2, JP170.5, R340.2, SJ253.2, SJ254.2, U85.P$6, U85.P$8
3.3V85: C171.1, C172.1, JP171.2, JP172.5, R344.2, SJ256.2, SJ257.2, U86.P$6, U86.P$8
3.3V86: C173.1, C174.1, JP173.2, JP174.5, R348.2, SJ259.2, SJ260.2, U87.P$6, U87.P$8
3.3V87: C175.1, C176.1, JP175.2, JP176.5, R352.2, SJ262.2, SJ263.2, U88.P$6, U88.P$8
3.3V88: C177.1, C178.1, JP177.2, JP178.5, R356.2, SJ265.2, SJ266.2, U89.P$6, U89.P$8
3.3V89: C179.1, C180.1, JP179.2, JP180.5, R360.2, SJ268.2, SJ269.2, U90.P$6, U90.P$8
3.3V90: C181.1, C182.1, JP181.2, JP182.5, R364.2, SJ271.2, SJ272.2, U91.P$6, U91.P$8
3.3V91: C183.1, C184.1, JP183.2, JP184.5, R368.2, SJ274.2, SJ275.2, U92.P$6, U92.P$8
3.3V92: C185.1, C186.1, JP185.2, JP186.5, R372.2, SJ277.2, SJ278.2, U93.P$6, U93.P$8
3.3V93: C187.1, C188.1, JP187.2, JP188.5, R376.2, SJ280.2, SJ281.2, U94.P$6, U94.P$8
3.3V94: C189.1, C190.1, JP189.2, JP190.5, R380.2, SJ283.2, SJ284.2, U95.P$6, U95.P$8
3.3V95: C191.1, C192.1, JP191.2, JP192.5, R384.2, SJ286.2, SJ287.2, U96.P$6, U96.P$8
3.3V96: C193.1, C194.1, JP193.2, JP194.5, R388.2, SJ289.2, SJ290.2, U97.P$6, U97.P$8
3.3V97: C195.1, C196.1, JP195.2, JP196.5, R392.2, SJ292.2, SJ293.2, U98.P$6, U98.P$8
3.3V98: C197.1, C198.1, JP197.2, JP198.5, R396.2, SJ295.2, SJ296.2, U99.P$6, U99.P$8
3.3V99: C199.1, C200.1, JP199.2, JP200.5, R400.2, SJ298.2, SJ299.2, U100.P$6, U100.P$8
!CS: JP2.1, R3.1, U1.P$2
!CS1: JP4.1, R7.1, U2.P$2
!CS2: JP6.1, R11.1, U3.P$2
!CS3: JP8.1, R15.1, U4.P$2
!CS4: JP10.1, R19.1, U5.P$2
!CS5: JP12.1, R23.1, U6.P$2
!CS6: JP14.1, R27.1, U7.P$2
!CS7: JP16.1, R31.1, U8.P$2
!CS8: JP18.1, R35.1, U9.P$2
!CS9: JP20.1, R39.1, U10.P$2
!CS10: JP22.1, R43.1, U11.P$2
!CS11: JP24.1, R47.1, U12.P$2
!CS12: JP26.1, R51.1, U13.P$2
!CS13: JP28.1, R55.1, U14.P$2
!CS14: JP30.1, R59.1, U15.P$2
!CS15: JP32.1, R63.1, U16.P$2
!CS16: JP34.1, R67.1, U17.P$2
!CS17: JP36.1, R71.1, U18.P$2
!CS18: JP38.1, R75.1, U19.P$2
!CS19: JP40.1, R79.1, U20.P$2
!CS20: JP42.1, R83.1, U21.P$2
!CS21: JP44.1, R87.1, U22.P$2
!CS22: JP46.1, R91.1, U23.P$2
!CS23: JP48.1, R95.1, U24.P$2
!CS24: JP50.1, R99.1, U25.P$2
!CS25: JP52.1, R103.1, U26.P$2
!CS26: JP54.1, R107.1, U27.P$2
!CS27: JP56.1, R111.1, U28.P$2
!CS28: JP58.1, R115.1, U29.P$2
!CS29: JP60.1, R119.1, U30.P$2
!CS30: JP62.1, R123.1, U31.P$2
!CS31: JP64.1, R127.1, U32.P$2
!CS32: JP66.1, R131.1, U33.P$2
!CS33: JP68.1, R135.1, U34.P$2
!CS34: JP70.1, R139.1, U35.P$2
!CS35: JP72.1, R143.1, U36.P$2
!CS36: JP74.1, R147.1, U37.P$2
!CS37: JP76.1, R151.1, U38.P$2
!CS38: JP78.1, R155.1, U39.P$2
!CS39: JP80.1, R159.1, U40.P$2
!CS40: JP82.1, R163.1, U41.P$2
!CS41: JP84.1, R167.1, U42.P$2
!CS42: JP86.1, R171.1, U43.P$2
!CS43: JP88.1, R175.1, U44.P$2
!CS44: JP90.1, R179.1, U45.P$2
!CS45: JP92.1, R183.1, U46.P$2
!CS46: JP94.1, R187.1, U47.P$2
!CS47: JP96.1, R191.1, U48.P$2
!CS48: JP98.1, R195.1, U49.P$2
!CS49: JP100.1, R199.1, U50.P$2
!CS50: JP102.1, R203.1, U51.P$2
!CS51: JP104.1, R207.1, U52.P$2
!CS52: JP106.1, R211.1, U53.P$2
!CS53: JP108.1, R215.1, U54.P$2
!CS54: JP110.1, R219.1, U55.P$2
!CS55: JP112.1, R223.1, U56.P$2
!CS56: JP114.1, R227.1, U57.P$2
!CS57: JP116.1, R231.1, U58.P$2
!CS58: JP118.1, R235.1, U59.P$2
!CS59: JP120.1, R239.1, U60.P$2
!CS60: JP122.1, R243.1, U61.P$2
!CS61: JP124.1, R247.1, U62.P$2
!CS62: JP126.1, R251.1, U63.P$2
!CS63: JP128.1, R255.1, U64.P$2
!CS64: JP130.1, R259.1, U65.P$2
!CS65: JP132.1, R263.1, U66.P$2
!CS66: JP134.1, R267.1, U67.P$2
!CS67: JP136.1, R271.1, U68.P$2
!CS68: JP138.1, R275.1, U69.P$2
!CS69: JP140.1, R279.1, U70.P$2
!CS70: JP142.1, R283.1, U71.P$2
!CS71: JP144.1, R287.1, U72.P$2
!CS72: JP146.1, R291.1, U73.P$2
!CS73: JP148.1, R295.1, U74.P$2
!CS74: JP150.1, R299.1, U75.P$2
!CS75: JP152.1, R303.1, U76.P$2
!CS76: JP154.1, R307.1, U77.P$2
!CS77: JP156.1, R311.1, U78.P$2
!CS78: JP158.1, R315.1, U79.P$2
!CS79: JP160.1, R319.1, U80.P$2
!CS80: JP162.1, R323.1, U81.P$2
!CS81: JP164.1, R327.1, U82.P$2
!CS82: JP166.1, R331.1, U83.P$2
!CS83: JP168.1, R335.1, U84.P$2
!CS84: JP170.1, R339.1, U85.P$2
!CS85: JP172.1, R343.1, U86.P$2
!CS86: JP174.1, R347.1, U87.P$2
!CS87: JP176.1, R351.1, U88.P$2
!CS88: JP178.1, R355.1, U89.P$2
!CS89: JP180.1, R359.1, U90.P$2
!CS90: JP182.1, R363.1, U91.P$2
!CS91: JP184.1, R367.1, U92.P$2
!CS92: JP186.1, R371.1, U93.P$2
!CS93: JP188.1, R375.1, U94.P$2
!CS94: JP190.1, R379.1, U95.P$2
!CS95: JP192.1, R383.1, U96.P$2
!CS96: JP194.1, R387.1, U97.P$2
!CS97: JP196.1, R391.1, U98.P$2
!CS98: JP198.1, R395.1, U99.P$2
!CS99: JP200.1, R399.1, U100.P$2
GND: C1.2, C2.2, JP1.1, JP2.6, SJ3.1, U1.P$1, U1.P$7
GND1: C3.2, C4.2, JP3.1, JP4.6, SJ6.1, U2.P$1, U2.P$7
GND2: C5.2, C6.2, JP5.1, JP6.6, SJ9.1, U3.P$1, U3.P$7
GND3: C7.2, C8.2, JP7.1, JP8.6, SJ12.1, U4.P$1, U4.P$7
GND4: C9.2, C10.2, JP9.1, JP10.6, SJ15.1, U5.P$1, U5.P$7
GND5: C11.2, C12.2, JP11.1, JP12.6, SJ18.1, U6.P$1, U6.P$7
GND6: C13.2, C14.2, JP13.1, JP14.6, SJ21.1, U7.P$1, U7.P$7
GND7: C15.2, C16.2, JP15.1, JP16.6, SJ24.1, U8.P$1, U8.P$7
GND8: C17.2, C18.2, JP17.1, JP18.6, SJ27.1, U9.P$1, U9.P$7
GND9: C19.2, C20.2, JP19.1, JP20.6, SJ30.1, U10.P$1, U10.P$7
GND10: C21.2, C22.2, JP21.1, JP22.6, SJ33.1, U11.P$1, U11.P$7
GND11: C23.2, C24.2, JP23.1, JP24.6, SJ36.1, U12.P$1, U12.P$7
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

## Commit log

2015-06-29 Made component and schematic
    [BME280_Breakout.sch]
2015-06-30 Pre-checklist commit
    [BME280_Breakout.brd, BME280_Breakout.sch]
2015-06-30 ready for QC check
    [BME280_Breakout.brd, BME280_Breakout.sch]
2015-07-01 Set isolate to 8 mil, added note
    [BME280_Breakout.brd]
2015-08-01 First working example, i2c and spi
2015-08-03 Rev 0.2
    [BME280_Breakout.brd, BME280_Breakout.sch]
2015-08-03 Rev 0.2, DRC fixed
    [BME280_Breakout.brd]
2015-08-03 Ready for review
    [BME280_Breakout.brd, BME280_Breakout.sch]
2015-08-04 fixed oversized via
    [BME280_Breakout.brd]
2015-08-24 incremented version number
    [BME280_Breakout.brd, BME280_Breakout.sch]
2015-08-24 Renamed boardfiles
    [SparkFun_BME280_Breakout.brd, SparkFun_BME280_Breakout.sch]
2015-08-27 created panel v10
    [SparkFun_BME280_Breakout_Panel_v10.brd]
2015-10-21 pushing final changes for review
    [RedboardI2C.fzz, RedboardSPI.fzz]
2015-10-21 Squashed 'Libraries/Arduino/' content from commit 373d5cd
    git-subtree-dir: Libraries/Arduino
    git-subtree-split: 373d5cd170aab532a42016c9282187b3efea6f02
2016-12-12 Pointed to new arduino library
2016-12-12 Squashed 'Libraries/Arduino/' changes from 9f6cbfb..d682b05
    3f71ec2 Updated documentation to reflect new pull
    fab9475 Merge pull request #5 from JamesWebb73/fix-float-precision
    c686b2c changed to divide return values
    git-subtree-split: d682b05838161ac95107d8356bb2c123ad7f4811
    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
2018-11-04 Removing library from repo.
    The library for this board is over here: https://github.com/sparkfun/SparkFun_BME280_Arduino_Library

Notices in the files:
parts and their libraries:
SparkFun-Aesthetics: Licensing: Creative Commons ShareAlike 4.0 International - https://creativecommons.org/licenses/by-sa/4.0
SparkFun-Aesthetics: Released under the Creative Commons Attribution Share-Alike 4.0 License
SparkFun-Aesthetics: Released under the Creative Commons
